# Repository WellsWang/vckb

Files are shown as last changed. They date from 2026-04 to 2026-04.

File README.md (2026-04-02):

# Vibe Coding Keyboard

## 简介

Vibe Coding Keyboard 是一个基于 ESP32-S3 的自定义键盘项目，支持 USB HID 键盘和鼠标功能。该键盘配备了一个 76x284 分辨率的 TFT-LCD 显示屏、9 个按键、1 个拨动开关和 1 个旋转编码器。通过配套的配置工具，可以灵活配置按键映射，支持多达 10 个键盘方案。



项目作者：Wells Wang (geek-logic.com)  
版本：0.1  
发布日期：2026/02/08  
许可证：GPL-3.0

## 功能特性

- **硬件核心**：ESP32-S3，具备原生 USB 接口
- **显示屏**：ST7789 驱动的 TFT-LCD，76x284 分辨率
- **输入设备**：
  - 9 个机械按键
  - 1 个拨动开关
  - 1 个旋转编码器（支持顺时针、逆时针和按下）
- **输出功能**：USB HID 键盘和鼠标
- **配置方案**：支持 10 个键盘映射方案，可切换激活
- **触发模式**：支持同时触发、顺序触发和粘滞触发
- **配置工具**：Python 桌面应用，支持实时配置和导入/导出配置

## 硬件要求

- ESP32-S3 开发板
- ST7789 TFT-LCD 显示屏 (76x284 分辨率)
- 9 个按键
- 1 个拨动开关
- 1 个旋转编码器
- 连接线和电源

### 引脚连接

#### LCD 显示屏 (ST7789)
- TFT_GND → GND
- TFT_VCC → 3.3V
- TFT_SCL → GPIO 12 (SCK)
- TFT_SDA → GPIO 11 (MOSI)
- TFT_RST → GPIO 9
- TFT_DC → GPIO 8
- TFT_CS → GPIO 10
- TFT_BL → GND

#### 按键和开关
- KEY0 → GPIO 3
- KEY1 → GPIO 4
- KEY2 → GPIO 5
- KEY3 → GPIO 6
- KEY4 → GPIO 7
- KEY5 → GPIO 14
- KEY6 → GPIO 15
- KEY7 → GPIO 16
- KEY8 → GPIO 17
- SW0 (拨动开关) → GPIO 38
- RT_BT (旋转编码器按钮) → GPIO 42
- RT_SA (旋转编码器 A) → GPIO 46
- RT_SB (旋转编码器 B) → GPIO 45

## 软件要求

- **固件**：
  - Arduino IDE
  - ESP32 板管理器
  - 所需库：Adafruit_GFX, Adafruit_ST7789, USB, USBHIDMouse, USBHIDKeyboard, EEPROM

- **配置工具**：
  - Python 3.x
  - Tkinter (通常随 Python 安装)
  - pyserial 库

## 安装和设置

### 固件烧录

1. 安装 Arduino IDE 和 ESP32 板管理器。
2. 安装所需库：Adafruit_GFX, Adafruit_ST7789, USBHID 等。
3. 打开 `src/Firmware/vckeyboard/vckeyboard.ino`。
4. 选择 ESP32-S3 板，设置 USB 模式为 USB-OTG。
5. 编译并上传固件到 ESP32-S3。

### 配置工具安装

1. 确保安装 Python 3.x。
2. 安装 pyserial：`pip install pyserial`
3. 运行 `src/Application/VCKBConfig.py`。

## 使用说明

1. 烧录固件后，键盘将作为 USB HID 设备连接到电脑。
2. 在正常使用模式长按旋转编码器可以进入设置模式，顺时针/逆时针旋转进行菜单项选择，短按旋转编码器为确定，长按旋转编码器为取消或这回退到上一级菜单。

## 远程配置工具

`VCKBConfig.py` 是一个基于 Tkinter 的桌面应用，提供以下功能：


- 串口选择和连接
- 读取/写入键盘配置
- 导入/导出二进制配置文件
- 实时预览和编辑按键映射
- 支持多方案管理

### 远程配置模式


1. 键盘在设置模式中选择`Remote Config`可以进入远程配置模式。
2. 键盘进入远程设置模式后，在PC端运行`VCKBConfig.py`可以进行远程设置。
3. 远程设置前，先要选择正确的串口端口号。
4. 默认的案件配置可以通过"导入"功能，读取同一文件夹下的`Default.bin`配置文件导入。
5. 点击"写入"将配置保存到键盘的 EEPROM。
6. 键盘将根据配置响应按键输入。

### 按键映射格式

每个按键支持：
- 短名称（最多 7 字符）
- 触发模式：同时触发、顺序触发、粘滞触发
- 最多 5 个键值组合（基于 USB HID 键值表）

## 项目结构

```
vckb/
├── 3D Models/                            # 外壳 3D 建模
│   ├── sketchup_src/                     # SketchUp 3D建模源文件
│   └── stl/                              # 3D 打印用模型文件
├── src/
│   ├── Application/                      # 配置工具
│   │   ├── VCKBConfig.py
│   │   └── Default.bin                   # 默认配置，供参考
│   ├── Firmware/                         # 固件代码
│   │   └── vckeyboard/
│   │       └── vckeyboard.ino
│   └── PCB/                              # 电路设计
│       ├── Gerbers/
│       │   └── VCKeyboard_Gerber_v1.zip  # PCB生产Gerber文件
│       ├── LCEDA_Project/                # EDA工程文件
│       │   └── VibeKeyboard.eprj2        # LCEDA电路设计工程源文件
│       └── Schematics/                   # 电路图
│           └── SCH_Schematic_v1.pdf      # 电路原理图
└── README.md                             # 本文件
```

## 后续计划

这个项目就是做着玩的，代码手搓没有很好的结构化，期待你参与开发一同完善，同时增加蓝牙和Wifi功能，做成无线键盘或者找到新的应用场景。

## 许可证

本项目基于 GPL-3.0 开源协议发布。欢迎使用、修改和分发，但请保留原作者信息和开源协议声明。

## 作者

Wells Wang  
网站：geek-logic.com  
邮箱：（请联系作者获取）

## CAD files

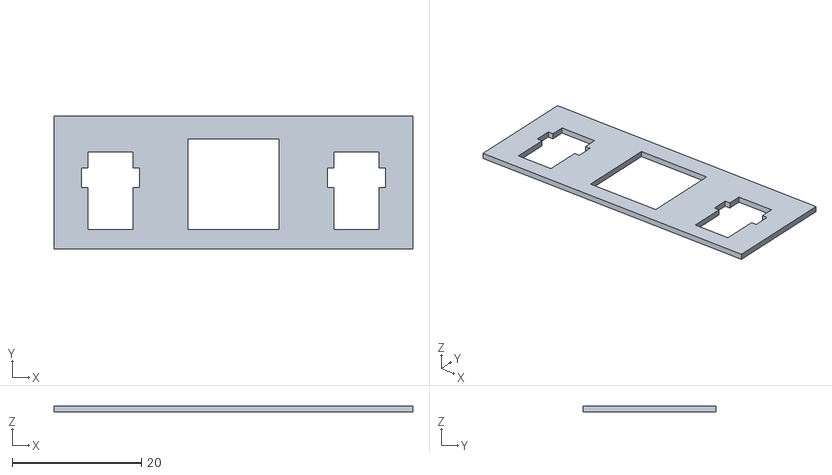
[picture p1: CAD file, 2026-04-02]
3D Models/stl/空格卫星轴定位板.stl
55.5 x 20.5 x 1.00

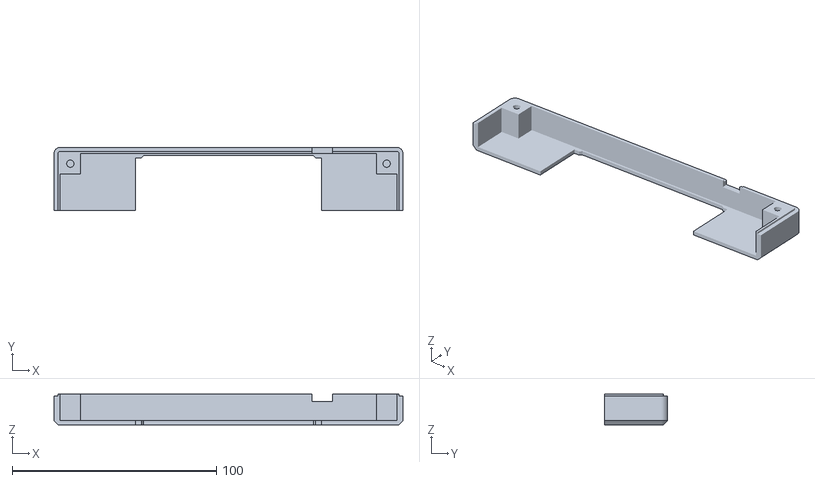
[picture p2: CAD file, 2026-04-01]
3D Models/stl/VibeCoding键盘上盖2.stl
171.0 x 31.0 x 15.0

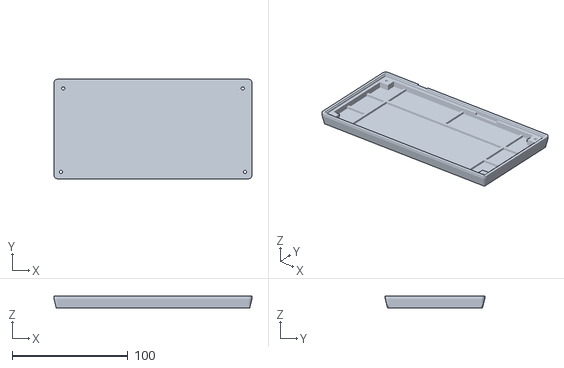
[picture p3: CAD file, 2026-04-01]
3D Models/stl/VibeCoding键盘底壳.stl
171.0 x 86.0 x 10.6

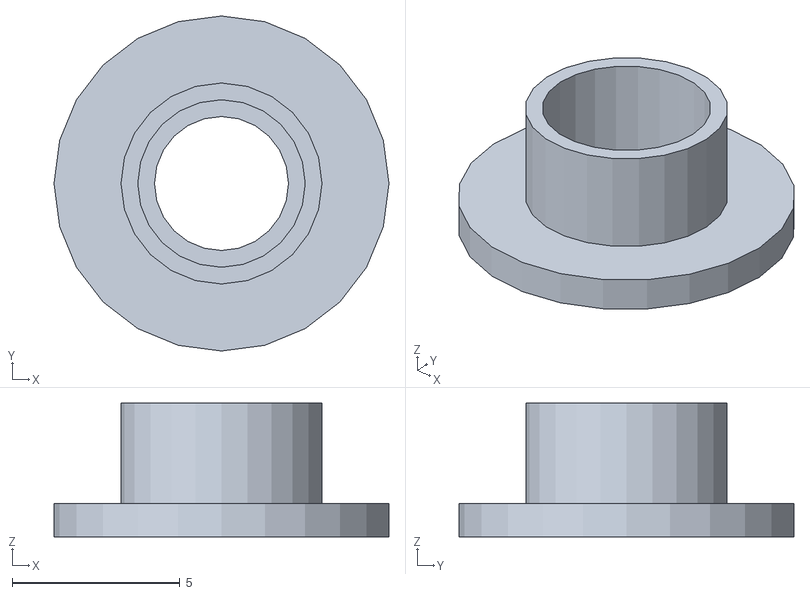
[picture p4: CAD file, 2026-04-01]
3D Models/stl/VibeCoding开关帽.stl
10.0 x 10.0 x 4.00

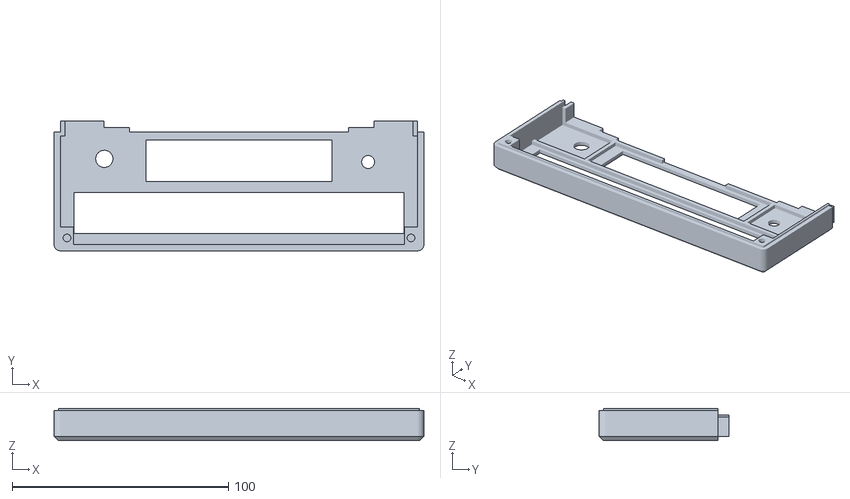
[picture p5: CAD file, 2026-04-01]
3D Models/stl/VibeCoding键盘上盖1.stl
171.0 x 60.0 x 15.0

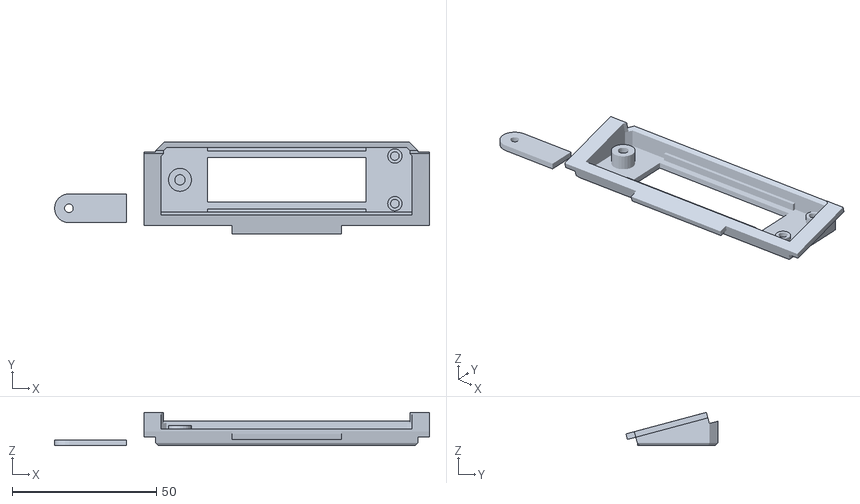
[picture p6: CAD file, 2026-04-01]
3D Models/stl/VibeCoding显示屏外壳.stl
130.0 x 31.9 x 11.6

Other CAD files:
3D Models/sketchup_src/开关帽.skp
3D Models/sketchup_src/显示屏外壳.skp
3D Models/sketchup_src/键盘上盖1.skp
3D Models/sketchup_src/键盘上盖2.skp
3D Models/sketchup_src/键盘底壳.skp

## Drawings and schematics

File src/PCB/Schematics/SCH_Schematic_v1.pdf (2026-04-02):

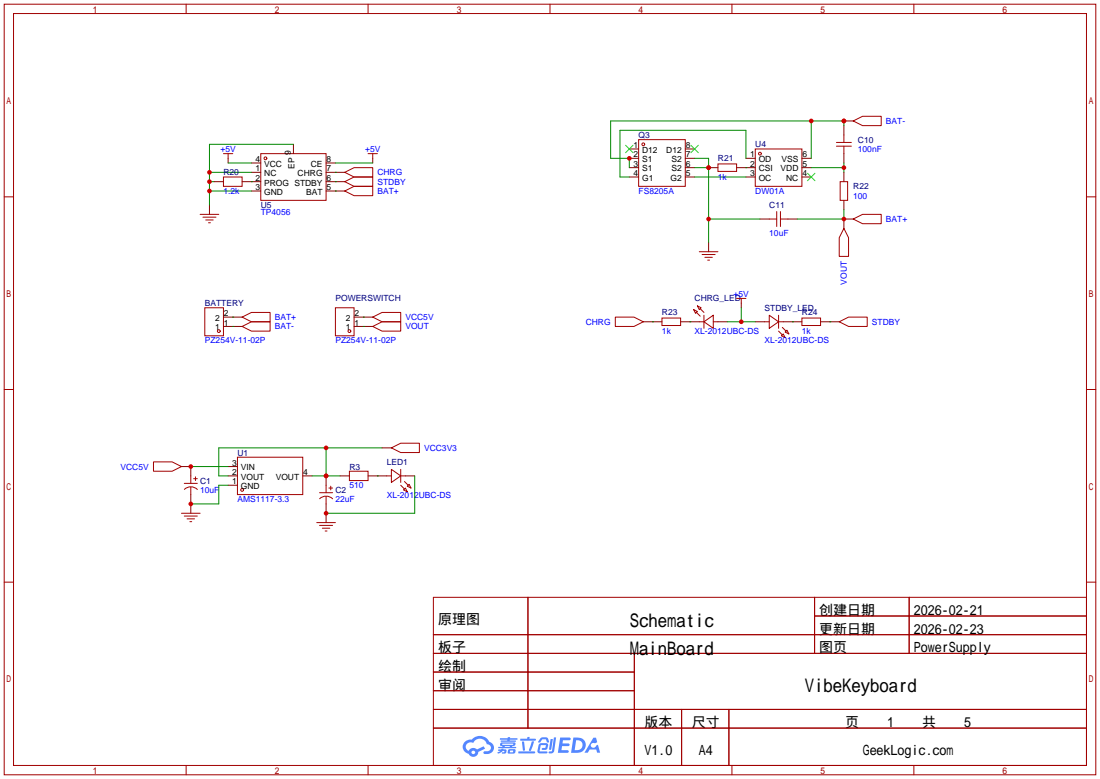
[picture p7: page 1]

原理图 | Schematic | 创建日期 | 2026-02-21

更新日期 | 2026-02-23

板子 | MainBoard | 图页 | PowerSupply
绘制 | | VibeKeyboard
审阅

V1.0 | A4 | GeekLogic.com

SBU2 B8 DN2 B7 DP2 B6 CC2 B5 VBUS B4A9 GND B1A12 SBU1 A8 DN1 A7 DP1 A6 CC1 A5 VBUS A4B9 GND A1B12

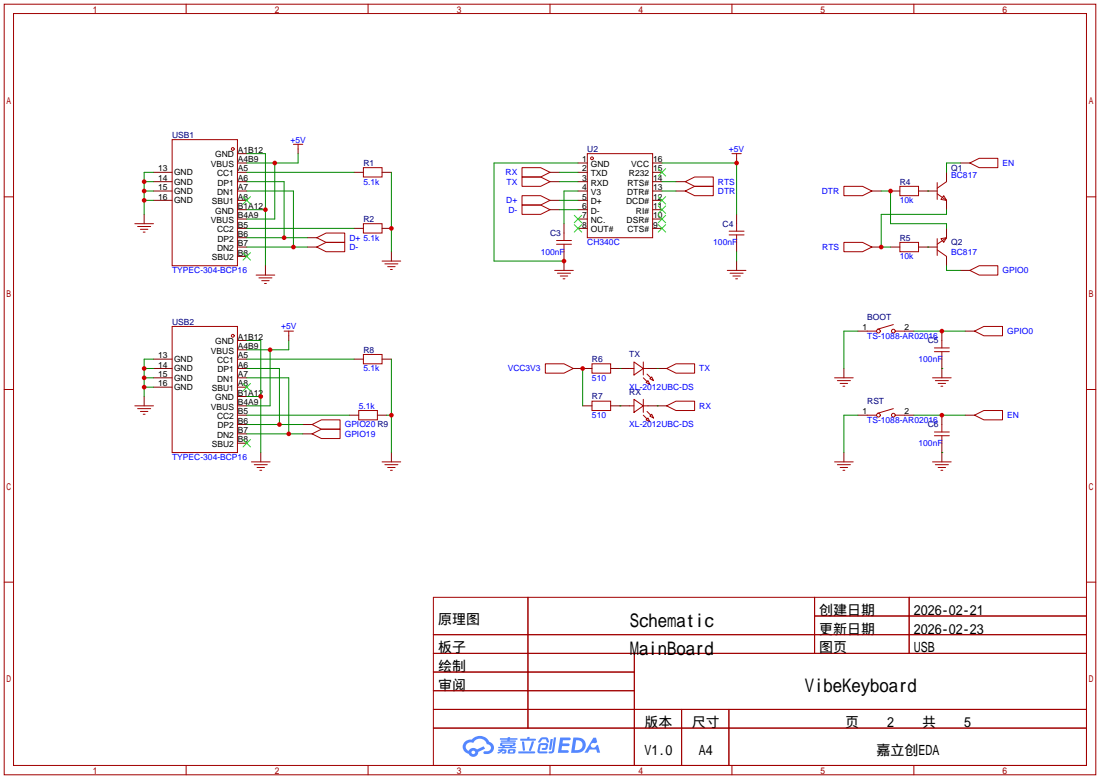
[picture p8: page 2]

DSR# 10 RI# 11 DCD# 12 DTR# 13 RTS# 14 R232 15 VCC 16

GND 16 GND 15 GND 14 GND 13

原理图 | Schematic | 创建日期 | 2026-02-21
板子 | MainBoard | 图页 | USB
绘制 | | VibeKeyboard
审阅

更新日期 | 2026-02-23

V1.0 | A4 | 嘉立创EDA

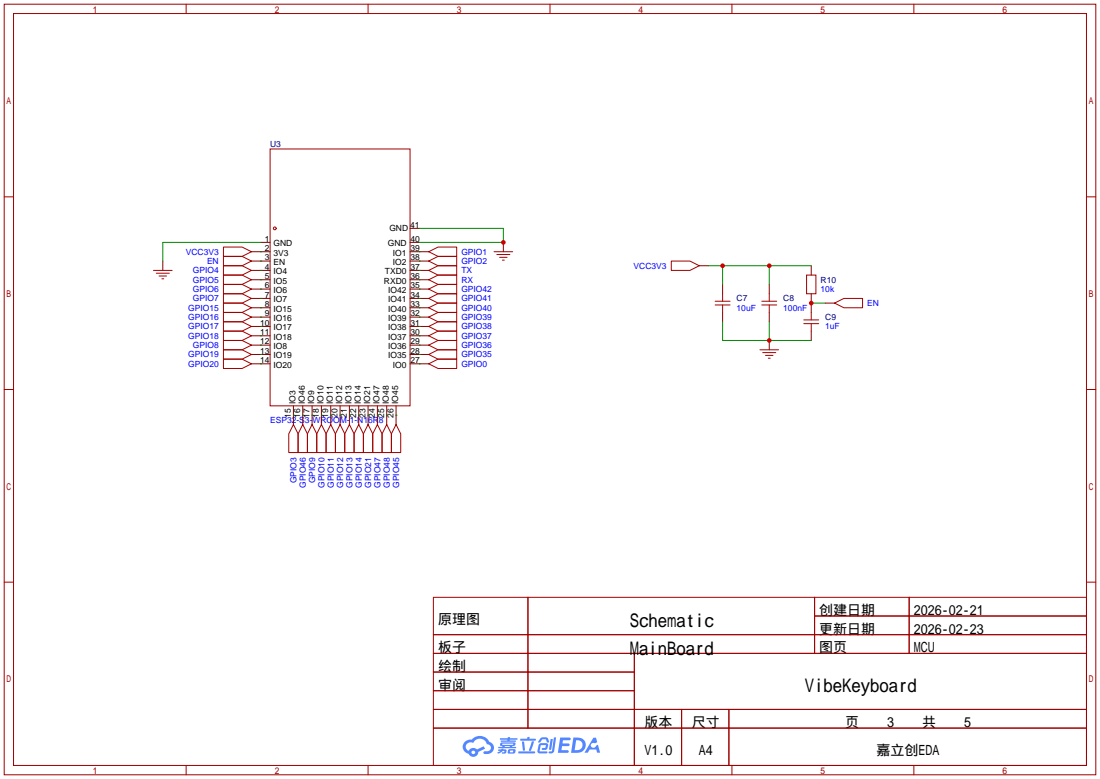
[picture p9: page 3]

原理图 | Schematic | 创建日期 | 2026-02-21
板子 | MainBoard | 图页 | MCU
绘制 | | VibeKeyboard
审阅

更新日期 | 2026-02-23

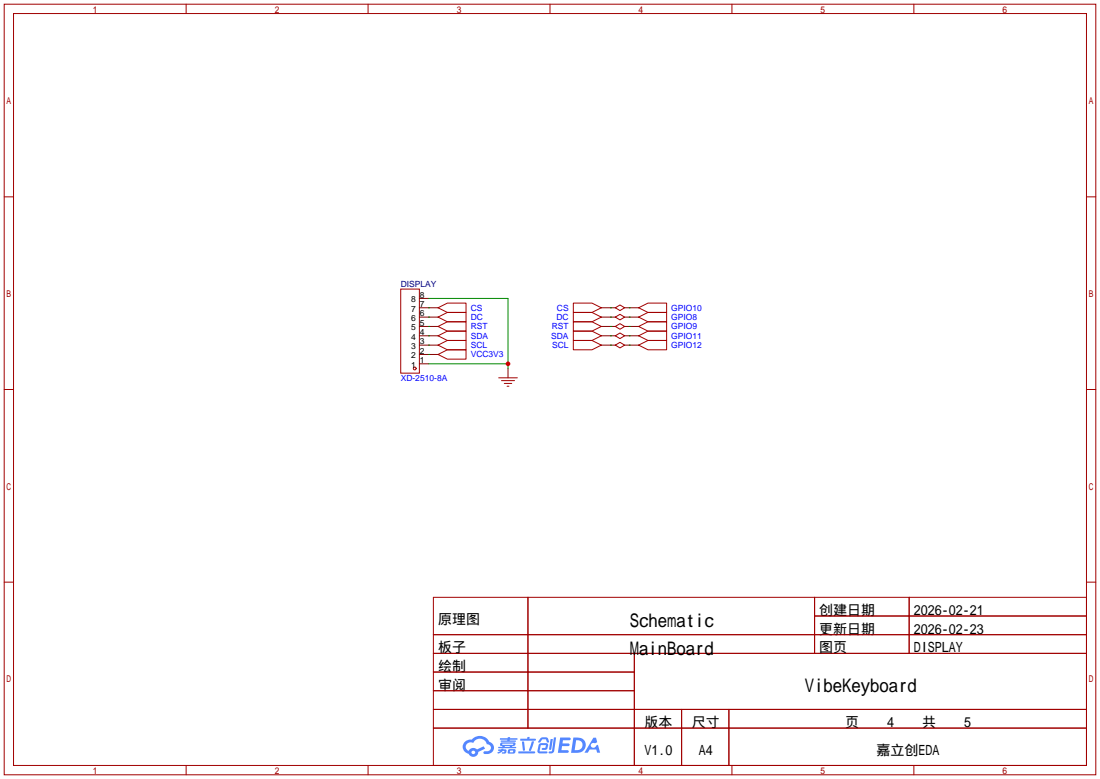
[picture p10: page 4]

原理图 | Schematic | 创建日期 | 2026-02-21

更新日期 | 2026-02-23

板子 | MainBoard | 图页 | DISPLAY
绘制 | | VibeKeyboard
审阅

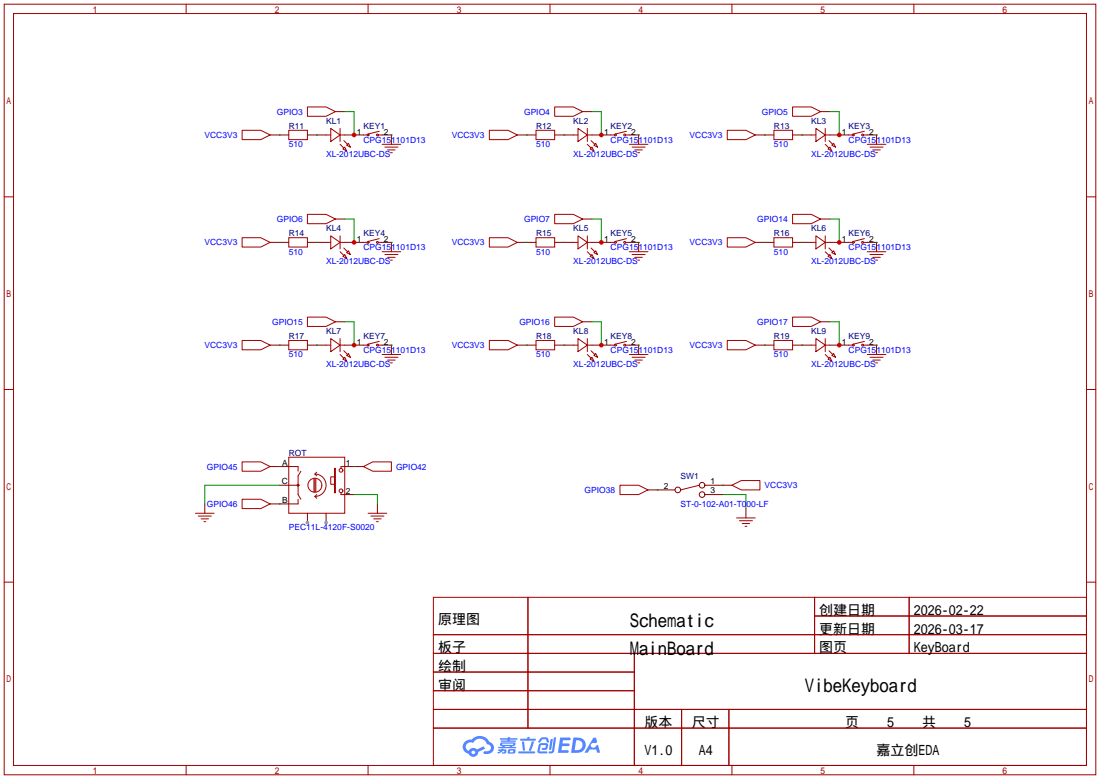
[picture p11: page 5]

原理图 | Schematic | 创建日期 | 2026-02-22

更新日期 | 2026-03-17

板子 | MainBoard | 图页 | KeyBoard
绘制 | | VibeKeyboard
审阅

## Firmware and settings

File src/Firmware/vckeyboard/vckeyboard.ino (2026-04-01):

/**************************************************************************
  Vibe Coding Keyboard
  ------------------------------------------------------------------------
  带有一个液晶显示屏的ESP32 S3 USB / 蓝牙自定义键盘

  液晶屏： 使用ST7789驱动的分辨率为76*284的TFT-LCD
  按键：
    拨动开关    x1
    按键        x9
    旋转编码器  x1
  
  硬件核心为 ESP32-S3，使用USB HID功能实现键盘和鼠标功能

  ------------------------------------------------------------------------
  
  作者： Wells Wang, geek-logic.com
  基于GPL-3.0开源协议发布，欢迎使用和修改，但请保留原作者信息和开源协议声明
  
  ------------------------------------------------------------------------
  
  版本 0.1 - 2026/02/08 初始版本，包含基本的显示和按键功能测试

 **************************************************************************/

///// EEPROM 设置
#include "EEPROM.h"
int addr = 0;
#define EEPROM_SIZE 2300     // EEPROM 大小，单位字节
#define EEPROM_VERSION 0x01 // EEPROM格式版本号，后续版本更新时可以通过修改此版本号来判断是否需要重新格式化EEPROM

///// LCD 设置
/**************************************************************************
LCD显示屏使用ST7789驱动，分辨率为76*284，连接方式为SPI接口
连接引脚：
  TFT_GND   - 连接到GND
  TFT_VCC   - 连接到3.3V
  TFT_SCL/K - 连接到数字引脚 12 (SCK)
  TFT_SDA   - 连接到数字引脚 11 (MOSI)
  TFT_RST   - 连接到数字引脚 9 (或设置为 -1 并连接到 Arduino RESET 引脚) 
  TFT_DC    - 连接到数字引脚 8 
  TFT_CS    - 连接到数字引脚 10
  TFT_BL    - 连接到GND
 **************************************************************************/
#include <Adafruit_GFX.h>    // Core graphics library
#include <Adafruit_ST7789.h> // Hardware-specific library for ST7789
#include <SPI.h>

#define TFT_CS        10
#define TFT_RST        9 // Or set to -1 and connect to Arduino RESET pin
#define TFT_DC         8
Adafruit_ST7789 tft = Adafruit_ST7789(TFT_CS, TFT_DC, TFT_RST); // 液晶屏幕

///// ESP32-S3 USB模式设置
#ifndef ARDUINO_USB_MODE
#error This ESP32 SoC has no Native USB interface
#elif ARDUINO_USB_MODE == 1
#warning This sketch should be used when USB is in OTG mode
void setup() {}
void loop() {}
#else

  #include "USB.h"
  #include "USBHIDMouse.h"
  #include "USBHIDKeyboard.h"
  USBHIDMouse Mouse;
  USBHIDKeyboard Keyboard;

  //按键引脚设置
  const int KEY0 = 3;
  const int KEY1 = 4;
  const int KEY2 = 5;
  const int KEY3 = 6;
  const int KEY4 = 7;
  const int KEY5 = 14;
  const int KEY6 = 15;
  const int KEY7 = 16;
  const int KEY8 = 17;

  const int SW0 = 38;     // 拨动开关
  const int RT_BT = 42;   // 旋转编码器按钮
  const int RT_SA = 46;   // 旋转编码器A
  const int RT_SB = 45;   // 旋转编码器B
  
  const unsigned long DEBOUNCE_MS = 15; // 按键去抖时间，单位毫秒
  
  // 按键状态结构体
  struct Key {
    uint8_t pin;
    bool lastState;        // 上一次读取的原始电平
    unsigned long lastChange; 
    bool pressed;          // 稳定的按下状态
  };

  // 定义按键数组，包含9个按键，初始状态为未按下（HIGH）
  Key keys[9] = {
    {KEY0, HIGH, 0, false},
    {KEY1, HIGH, 0, false},
    {KEY2, HIGH, 0, false},
    {KEY3, HIGH, 0, false},
    {KEY4, HIGH, 0, false},
    {KEY5, HIGH, 0, false},
    {KEY6, HIGH, 0, false},
    {KEY7, HIGH, 0, false},
    {KEY8, HIGH, 0, false}
  };

  int key_history[3] = {-1, -1, -1};  // 按键历史记录

  // 键值映射结构体
  struct Key_Value {
    String name;
    byte value;
  };

  // 键值映射表，包含常用键盘按键和功能键
  Key_Value key_val[105] = {
    {"None", 0x00},
    {"`", 0x60},
    {"1", 0x31},
    {"2", 0x32},
    {"3", 0x33},
    {"4", 0x34},
    {"5", 0x35},
    {"6", 0x36},
    {"7", 0x37},
    {"8", 0x38},
    {"9", 0x39},
    {"0", 0x30},
    {"-", 0x2D},
    {"=", 0x3D},
    {"Space", 0x20},
    {"A", 0x61},
    {"B", 0x62},
    {"C", 0x63},
    {"D", 0x64},
    {"E", 0x65},
    {"F", 0x66},
    {"G", 0x67},
    {"H", 0x68},
    {"I", 0x69},
    {"J", 0x6A},
    {"K", 0x6B},
    {"L", 0x6C},
    {"M", 0x6D},
    {"N", 0x6E},
    {"O", 0x6F},
    {"P", 0x70},
    {"Q", 0x71},
    {"R", 0x72},
    {"S", 0x73},
    {"T", 0x74},
    {"U", 0x75},
    {"V", 0x76},
    {"W", 0x77},
    {"X", 0x78},
    {"Y", 0x79},
    {"Z", 0x7A},
    {"[", 0x5B},
    {"]", 0x5D},
    {"\\", 0x5C},
    {";", 0x3B},
    {"'", 0x27},
    {",", 0x2C},
    {".", 0x2E},
    {"/", 0x2F},
    {"Left Ctrl", 0x80},
    {"Left Shift", 0x81},
    {"Left Alt", 0x82},
    {"Left GUI", 0x83},
    {"Right Ctrl", 0x84},
    {"Right Shift", 0x85},
    {"Right Alt", 0x86},
    {"Right GUI", 0x87},
    {"Up Arrow", 0xDA},
    {"Down Arrow", 0xD9},
    {"Left Arrow", 0xD8},
    {"Right Arrow", 0xD7},
    {"Menu", 0xED},
    {"Backspace", 0xB2},
    {"Tab", 0xB3},
    {"Return", 0xB0},
    {"ESC", 0xB1},
    {"Insert", 0xD1},
    {"Delete", 0xD4},
    {"Page Up", 0xD3},
    {"Page Down", 0xD6},
    {"Home", 0xD2},
    {"End", 0xD5},
    {"Num Lock", 0xDB},
    {"Caps Lock", 0xC1},
    {"F1", 0xC2},
    {"F2", 0xC3},
    {"F3", 0xC4},
    {"F4", 0xC5},
    {"F5", 0xC6},
    {"F6", 0xC7},
    {"F7", 0xC8},
    {"F8", 0xC9},
    {"F9", 0xCA},
    {"F10", 0xCB},
    {"F11", 0xCC},
    {"F12", 0xCD},
    {"Print Screen", 0xCE},
    {"Scroll Lock", 0xCF},
    {"Pause", 0xD0},
    {"Keypad /", 0xDC},
    {"Keypad *", 0xDD},
    {"Keypad -", 0xDE},
    {"Keypad +", 0xDF},
    {"Keypad Enter", 0xE0},
    {"Keypad 1", 0xE1},
    {"Keypad 2", 0xE2},
    {"Keypad 3", 0xE3},
    {"Keypad 4", 0xE4},
    {"Keypad 5", 0xE5},
    {"Keypad 6", 0xE6},
    {"Keypad 7", 0xE7},
    {"Keypad 8", 0xE8},
    {"Keypad 9", 0xE9},
    {"Keypad 0", 0xEA},
    {"Keypad .", 0xEB}
  };

  // 旋转编码器状态结构体
  struct RotateEncoder  {
    int pinA;
    int pinB;
    int pinBtn;
    bool lastStateA;
    bool lastStateB;
    bool lastStateBtn;
    bool pressed;
    unsigned long lastChangeA;
    unsigned long lastChangeB;
    unsigned long lastPressedBtn;
    unsigned long lastReleasedBtn;
  };

  // 定义旋转编码器，初始状态为未按下（HIGH）
  RotateEncoder rotEnc = {RT_SA, RT_SB, RT_BT, HIGH, HIGH, HIGH, false, 0, 0, 0, 0};
  #define ROT_ENC_LONG_PRESS_MS 1000 // 旋转编码器按钮长按时间，单位milliseconds
  

  byte keymap[12][6]; // 12个按键设置，每个按键最多支持5个键值的组合，每个键值1字节，前面1字节表示同时激活或顺序按下
  String currentSchemeName = "Scheme 1";
  
  bool needDisplayRefresh = true;

  // 菜单项结构体，包含菜单名称、操作函数和父菜单ID
  struct MenuItem {
    String name;
    void (*action)();
    int parentId; // 父菜单ID，-1表示顶级菜单
    byte subMode; // 子功能的模式
                  // subMode的值可以根据需要定义不同的功能模式，例如：
                  // 0：普通USB模式，正常运行中
                  // 1: 蓝牙模式，和普通USB模式一样，仅激活了蓝牙连接
                  // 2: 网络设置模式，进入后显示网络IP地址等信息可以通过访问网页进行配置
                  // 3：菜单操作界面，显示菜单操作界面
                  // 11：激活方案界面，显示当前方案列表，可以选择要激活的方案
                  // 12：修改方案界面，显示当前方案列表，可以选择要修改的方案
                  // 13：蓝牙设置界面，显示蓝牙设置选项，可以选择要修改的蓝牙设置
                  // 14：网络设置界面，显示网络设置选项，可以选择要修改的网络设置
  };

  void switchScheme();        // 前向声明激活方案的函数，以便在菜单项中使用
  void modifySchemeName();    // 前向声明修改方案名称的函数，以便在菜单项中使用
  void setKeyShortName();     // 前向声明修改按键短名称的函数，以便在菜单项中使用
  void toggleActive();        // 前向声明切换激活方案的函数，以便在菜单项中使用
  void toggleTriggerMode();   // 前向声明切换触发模式的函数，以便在菜单中使用
  void selectKey();           // 前向声明选择按键值得函数，以便在菜单项中使用
  void remoteConfigMode();    // 前向声明远程配置模式函数，以便在菜单项中使用

  // 定义菜单项，包含顶级菜单和子菜单
  #define MENU_SIZE 41
  #define IDX_SCHEME_START 8
  #define IDX_KEY_START 21
  #define IDX_KEY_VALUE_START 36

  MenuItem menu[MENU_SIZE] ={                                 // ID
    {"Normal", nullptr, -1, 0},                               // 0
    {"Settings", nullptr, -1, 3},                             // 1
    {"Remote Config",  remoteConfigMode, -1, 2},              // 2
    {"Primary Scheme", switchScheme, 1, 11},                  // 3
    {"Secondary Scheme", switchScheme, 1, 12},                // 4
    {"Modify Scheme", nullptr, 1, 4},                         // 5
    {"Bluetooth Settings", [](){}, 1, 13},                    // 6
    {"Network Settings", [](){}, 1, 14},                      // 7
    {"Scheme 1", nullptr, 5, 3},                              // 8
    {"Scheme 2", nullptr, 5, 3},                              // 9  
    {"Scheme 3", nullptr, 5, 3},                              // 10
    {"Scheme 4", nullptr, 5, 3},                              // 11
    {"Scheme 5", nullptr, 5, 3},                              // 12
    {"Scheme 6", nullptr, 5, 3},                              // 13
    {"Scheme 7", nullptr, 5, 3},                              // 14
    {"Scheme 8", nullptr, 5, 3},                              // 15
    {"Scheme 9", nullptr, 5, 3},                              // 16
    {"Scheme 10", nullptr, 5, 3},                             // 17
    {"Scheme Name", modifySchemeName, 8, 21},                 // 18
    {"Active / Deactive", toggleActive, 8, 25},               // 19
    {"Key Mapping", nullptr, 8, 5},                           // 20
    {"Key 1", nullptr, 20, 3},                                // 21
    {"Key 2", nullptr, 20, 3},                                // 22
    {"Key 3", nullptr, 20, 3},                                // 23
    {"Key 4", nullptr, 20, 3},                                // 24
    {"Key 5", nullptr, 20, 3},                                // 25
    {"Key 6", nullptr, 20, 3},                                // 26
    {"Key 7", nullptr, 20, 3},                                // 27
    {"Key 8", nullptr, 20, 3},                                // 28
    {"Key 9", nullptr, 20, 3},                                // 29
    {"RotEnc Clockwise", nullptr, 20, 3},                     // 30
    {"RotEnc Counter Clockwise", nullptr, 20, 3},             // 31
    {"RotEnc Button", nullptr, 20, 3},                        // 32
    {"Modify Key Value", nullptr, 21, 3},                     // 33
    {"Set Trigger Mode", toggleTriggerMode, 21, 31},          // 34
    {"Set Key Name", setKeyShortName, 21, 32},                // 35
    {"Key Value 1", selectKey, 33, 35},                       // 36
    {"Key Value 2", selectKey, 33, 35},                       // 37
    {"Key Value 3", selectKey, 33, 35},                       // 38
    {"Key Value 4", selectKey, 33, 35},                       // 39
    {"Key Value 5", selectKey, 33, 35},                       // 40
  };

  int currentMenuId = 1; // 当前菜单ID，初始为0
  int prevMenuId = 0;   // 上一个菜单ID
  int nextMenuId = 0;   // 下一个菜单ID
  int currentMode = 0;     // 当前功能模式，初始为0

  byte currentSchemeId = 1; // 当前激活的方案ID，初始为1
  byte schemeId = 1;    // 当前正在修改的方案ID，初始为1
  byte nextSchemeId = 1;    // 下一个方案ID
  byte prevSchemeID = 1;
  byte activeSchemeId;
  int pos = 0; // 当前输入位置
  bool isActive; // 当前方案是否激活
  bool primary = true; // 是否为主方案，方案切换用
  byte keyId = 0;
  int keyIndex = 0; //当前键值索引
  #define KEY_INTERVAL 50   //顺序按键间隔时间ms
  #define KEY_SHORT_NAME_LENGTH 7 // 按键短名称字符串长度

  byte serialMode = 'N';      // 串口模式，N 未连接，W 等待链接，R 接收，T 发送
  unsigned long serialStart = 0;        // 串口开始发送接收时间
  int bytesCount = 0;         // 串口接收数据计数器
  char configData[EEPROM_SIZE];   // 配置数据
  #define SER_TIMEOUT 60      // 串口信息发送接收timeout时长，60秒

  struct Scheme {
    String name;
    bool active;
    byte keymap[12][6];
    String keyname[12];
  };
  Scheme schemes[10]; // 最多支持10组方案



  //////////////////// DATA 相关 ////////////////////
  
  // 格式化EEPROM
  void formatEEPROM() {
    /*
      EEPROM存储信息格式：
      地址范围      内容
      0             当前激活的键盘方案ID，1字节，默认值 0x01，即方案1
      1             键盘方案的总数量，1字节，默认值 0x0A , 10组方案
      2             设置顺序按下时的时间间隔，单位10毫秒，1字节，默认值 0x05，即50毫秒
      3             快速切换的第二套方案ID，1字节，默认值0x01，即方案1
      4-94          保留空间，未来存放蓝牙、网络等配置信息
      95            EEPROM格式版本号，1字节，默认值0x01，后续版本更新时可以通过修改此版本号来判断是否需要重新格式化EEPROM
      
      // 后续共10组96字节，每组表示一个方案的按键映射内容
      96-191        方案1的按键映射内容，96字节
        96字节内容格式：
          0         是否激活此方案，0不激活，1激活，1字节，默认值只有方案1为1，其余为0
          1-23      方案名称，23字节，最多支持23个字符的方案名称，超过部分会被截断，默认值为"Scheme {ID}"
          24-95     方案的按键映射内容，72字节，共9个按键加旋转编码器的两个方向和一个按键的设置（12个设置），每个按键6个字节
            每个按键的6字节内容格式：
              0         同时激活或顺序按下，0为同时激活，1为顺序按下，1字节，后续扩展可能增加更多的激活方式，默认值为0
              1-5       5个键值，每个1字节，表示按键按下时要发送的键值，最多支持5个键值的组合，超过部分会被忽略，键值参考USB HID键盘使用的键值表，0表示无按键，默认值为0

      192-287       方案2的按键映射内容，96字节
      ...
      960-1055       方案10的按键映射内容，96字节  
      1056-1099     保留空间
      1100-2299     1200字节按键短名称，10个按键配置方案，每个方案12个按键，每个按键10字节空间
        1100-1219   120个字节 方案一的按键短名称
          1100-1109 方案一的第一个按键的短名称
          ...
          1210-1219 方案二的第十二个按键的短名称
          ...
          ...
          ...
    */

    // 初始化EEPROM内容
    // 地址0：当前激活的键盘方案ID，默认值0x01（方案1）
    EEPROM.write(0, 0x01);
    
    // 地址1：键盘方案总数，默认值0x0A（10组方案）
    EEPROM.write(1, 0x0A);
    
    // 地址2：顺序按下时的时间间隔（单位10毫秒），默认值0x05（50毫秒）
    EEPROM.write(2, 0x05);

    // 地址3：快速切换的第二套方案ID，默认值0x01（方案1），两套方案相同表示不切换
    EEPROM.write(3, 0x01);
    
    // 地址4-95：保留空间，初始化为0
    for (int i = 4; i < 95; i++) {
      EEPROM.write(i, 0);
    }
    
    // 地址95：EEPROM格式版本号
    EEPROM.write(95, EEPROM_VERSION);

    // 地址96-1055：10组方案数据，每组96字节
    for (int scheme = 0; scheme < 10; scheme++) {
      int baseAddr = 96 + scheme * 96;
      
      // 第0字节：是否激活此方案（只有方案1激活）
      EEPROM.write(baseAddr, (scheme == 0) ? 1 : 0);
      
      // 第1-23字节：方案名称
      String schemeName = "Scheme " + String(scheme + 1);
      for (int j = 0; j < 23; j++) {
      EEPROM.write(baseAddr + 1 + j, (j < schemeName.length()) ? schemeName[j] : 0);
      }
      
      // 第24-95字节：按键映射内容（12个按键×6字节），初始化为0
      for (int i = 24; i < 96; i++)
        EEPROM.write(baseAddr + i, 0);
      
      // 初始化按键短名称
      for (int i = 0; i < 120; i++) 
        EEPROM.write(1100 + scheme * 120 + i, 0);
    }
    EEPROM.commit();
  }

  //读取当前按键方案名称
  String getSchemeName(byte id) {
    /*
      读取指定ID的方案名称
      参数：
        id：方案ID，范围1-10，对应EEPROM中地址96-1055的10组方案数据
      返回值：
        方案名称字符串，最多支持23个字符，超过部分会被截断
    */
    if (id < 1 || id > 10) {
      Serial.println("Invalid scheme ID");
      return "";
    }
    int baseAddr = id * 96;
    String schemeName = "";
    for (int i = 0; i < 23; i++) {
      char c = EEPROM.read(baseAddr + 1 + i);
      if (c == 0) break; // 遇到字符串结束符
      schemeName += c;
    }
    return schemeName;
  }

  //读取按键短名称

  String getKeyShortName(byte scheme_id, byte key_id){
    /*
      获取按键的短名称
      
      从EEPROM中读取指定方案和按键的短名称。如果未设置名称或名称为空，
      则返回默认名称 "KEYx"（x为按键ID）。
      
      参数：
      scheme_id 方案ID，用于定位EEPROM中不同方案的存储位置
      key_id 按键ID，用于定位该方案内的特定按键
      
      返回值：
      String 按键的短名称，长度最多为KEY_SHORT_NAME_LENGTH个字符，
            如果未设置则返回默认名称"KEYx"
    
      细节说明：
        - 基础地址：1100
        - 地址计算：baseAddr + scheme_id * 120 + key_id * 10 + i
        - 每个按键分配10字节空间存储短名称
        - 字符串以null终止符(0)或达到最大长度时结束
      
      注意： 确保scheme_id和key_id的有效性，避免越界访问EEPROM
    */
    int baseAddr = 1100;
    String short_name = "";
    for (int i = 0 ; i < 10 ; i++){
      char c = EEPROM.read(baseAddr + scheme_id * 120 + key_id * 10 + i);
      if (c==0 || i == KEY_SHORT_NAME_LENGTH) break; // 字符串结束或超过最大长度
      short_name += c;
    }
    if (short_name == "") short_name = "KEY" + String(key_id); //默认名称
    return short_name;
  }
  
  void getSchemeList() {
    /*
      获取所有方案的名称和激活状态，并存储在全局变量schemes数组中
      参数：
        无
      返回值：
        无，获取到的方案信息会存储在全局变量schemes数组中
    */
    for (byte id = 1; id <= 10; id++) {
      int baseAddr = id * 96;
      schemes[id - 1].active = (EEPROM.read(baseAddr) == 1);
      schemes[id - 1].name = getSchemeName(id);
      menu[IDX_SCHEME_START - 1 + id].name = schemes[id - 1].name; // 更新菜单项名称
      for (int i = 0; i < 12; i++) {
        for (int j = 0; j < 6; j++) {
          schemes[id - 1].keymap[i][j] = EEPROM.read(baseAddr + 24 + i * 6 + j);
        }
        schemes[id - 1].keyname[i] = getKeyShortName(id -1, i);
      }
    }
  }

  byte findActiveSchemeId(byte curId, bool direction){
    /*
      在EEPROM中查找下一个或上一个激活的方案ID
      参数：
        curId：当前方案ID，范围1-10
        direction：查找方向，true表示顺时针（下一个），false表示逆时针（上一个）
      返回值：
        下一个或上一个激活的方案ID，如果没有找到则返回当前方案ID 
    */
    int startAddr = curId * 96; // 当前方案的EEPROM地址
    int step = direction ? 96 : -96; // 步长，根据方向决定是向后还是向前查找
    int addr = startAddr; // 从当前方案开始查找
    do {
      addr += step; // 移动到下一个或上一个方案的地址
      if (addr < 96) {
        addr = 960; // 如果越过第一个方案，则跳转到最后一个方案
      } else if (addr > 960) {
        addr = 96; // 如果越过最后一个方案，则跳转到第一个方案
      }
      if (EEPROM.read(addr) == 1) { // 检查该方案是否激活
        return byte (addr / 96) ; // 返回找到的激活方案ID
      }
    } while (addr != startAddr); // 如果回到起始地址，说明没有找到其他激活的方案
    return curId; // 没有找到其他激活的方案，返回当前方案ID
  }

  void updateMenuParentID(int menu_id, int start_idx, int end_idx){
    /*
      更新菜单项的父菜单ID，将指定范围内的菜单项的父菜单ID设置为指定的菜单ID
      参数：
        menu_id：新的父菜单ID
        start_idx：起始索引
        end_idx：结束索引
      返回值：无
    */
    for (int i = start_idx; i < end_idx; i++) 
      menu[i].parentId = menu_id; // 将修改按键映射的菜单项的父菜单ID
  }

  // 更新按键历史记录
  void updateKeyHistory(int key_index){
    /*
      更新按键历史记录，将最新的按键索引添加到历史记录中
      参数：
        key_index：按键索引
      返回值：无
    */
    key_history[0] = key_history[1];
    key_history[1] = key_history[2];
    key_history[2] = key_index;
  }

  // 根据键值获取键号索引
  int getKeyCodeIndex(byte val){
    /*
      根据键值查找对应的键号索引
      参数：
        val：键值
      返回值：键号索引，如果未找到返回-1
    */
    for (int i = 0; i < 105; i++){
      if (key_val[i].value == val)
        return i;  
    }
    return -1;
  }


  //////////////////// UI相关 ////////////////////

  // 绘制菜单项
  void drawMenuItem(int selectedId) {
    /*
      绘制指定父菜单ID下的菜单项列表
      如果菜单项数目大于三项，则需要实现滚动显示功能，尽可能让选中项显示在屏幕中间，并且在选中项上方和下方各显示一个菜单项，如果选中项在顶部或底部，则优先显示选中项和其相邻的两个菜单项
      同时更新prevMenuId和nextMenuId变量，以便在用户按下旋转编码器时能够正确地切换菜单项。
      当选中项为第一项时，prevMenuId应该指向最后一项，nextMenuId指向第二项；当选中项为最后一项时，prevMenuId应该指向倒数第二项，nextMenuId指向第一项；其他情况下prevMenuId指向选中项的前一项，nextMenuId指向选中项的后一项。
      参数：
        parentId：父菜单ID，-1表示顶级菜单
        selectedId：当前选中的菜单项ID
      返回值：
        无，菜单项会直接绘制到屏幕上
    */
   
    // 找到所有属于该父菜单的菜单项
    int menuItems[MENU_SIZE];
    int menuCount = 0;
    for (int i = 0; i < MENU_SIZE; i++) {
      if (menu[i].parentId == menu[selectedId].parentId) {
        menuItems[menuCount++] = i;
      }
    }
    
    if (menuCount == 0) return;
    
    // 找到选中项在该父菜单中的索引
    int selectedIndex = -1;
    for (int i = 0; i < menuCount; i++) {
      if (menuItems[i] == selectedId) {
      selectedIndex = i;
      break;
      }
    }
    if (selectedIndex == -1) selectedIndex = 0;
    
    // 更新prevMenuId和nextMenuId
    currentMenuId = selectedId;
    prevMenuId = menuItems[(selectedIndex - 1 + menuCount) % menuCount];
    nextMenuId = menuItems[(selectedIndex + 1) % menuCount];
    
    // 确定显示的起始项索引
    int startIndex = (selectedIndex - 1 + menuCount) % menuCount;

    // 绘制菜单项（最多显示3项）
    tft.setTextSize(1);
    int displayCount = (menuCount > 3) ? 3 : menuCount;
    int i;
    for (i = 0; i < displayCount; i++) {
      int itemIndex = (startIndex + i) % menuCount;
      int itemId = menuItems[itemIndex];
      bool isSelected = (itemIndex == selectedIndex);
      
      tft.setTextColor(isSelected ? ST77XX_RED : ST77XX_WHITE);
      tft.fillRect(0, 20 + i * 16, tft.width(), 20, isSelected ? ST77XX_WHITE : ST77XX_BLACK);
      tft.setCursor(10, 24 + i * 16 );
      tft.print(menu[itemId].name);
    }

    for (; i < 3; i++) {
      tft.fillRect(0, 20 + i * 16, tft.width(), 20, ST77XX_BLACK);
    }

  }

  void drawSubMenu(int id){
    /*
      绘制指定ID的子菜单项
      参数：
        id：菜单项ID
      返回值：无
    */
    for (int i = 0; i < MENU_SIZE; i++) {
      if ( menu[i].parentId == id) {
        drawMenuItem(i);
        break;
      }
    }
  }

  void drawSaveButton(bool inverse){
    /*
      绘制保存按钮，根据inverse参数决定是否反白显示
      参数：
        inverse：是否反白显示，true表示反白显示，false表示正常显示
      返回值：无
    */
    tft.fillRect(240, 60, 40, 16, inverse ? ST77XX_WHITE : ST77XX_BLACK);
    if (!inverse) {
      tft.drawRect(240, 60, 40, 16, ST77XX_WHITE); // 画边框
    } 
    tft.setCursor(248, 64);
    tft.setTextColor(inverse ? ST77XX_RED : ST77XX_WHITE);
    tft.print("Save");
  }

  char updateCurrentText(char currentChar, int direction, bool inverse = true) {
    /*
      更新当前选择字符的显示，同时更新schemes中对应方案名称的字符，以便在修改方案名称时能够实时预览输入的效果
      根据pos（当前第几个字符）来确定屏幕上显示的位置，以及确定schemes中对应方案名称中的第几个字符，当前正在修改的字符反白显示。
      修改的字符为当前位置的下一个或前一个字符（ASCII码），可用于修改的ASCII字符范围为32-126，超过范围时循环回到起始或结束位置。
      参数：
        currentChar: 当前的字符
        direction：方向，1 表示当前字符下一个字符，-1 表示前一个字符, 0表示当前字符
      返回值：  变更后的字符，更新后的文本会直接显示在屏幕上
    */
    //char currentChar = currentSchemeName[pos]; // 获取当前字符

    if (currentChar < 32 || currentChar > 126) currentChar = 32;

    if (direction == 1) {
      currentChar++; // 向下一个字符移动
      if (currentChar > 126) currentChar = 32; // 如果超出范围，循环到起始字符
    } else if (direction == -1) {
      currentChar--; // 向前一个字符移动
      if (currentChar < 32) currentChar = 126; // 如果超出范围，循环到结束字符
    }

    //currentSchemeName[pos] = currentChar; // 更新currentSchemeName中的字符

    // 在屏幕上更新显示
    tft.fillRect(10 + pos * 6, 36, 6, 16, (inverse ? ST77XX_WHITE : ST77XX_BLACK));
    tft.setCursor(10 + pos * 6, 40);
    tft.setTextColor(inverse ? ST77XX_RED : ST77XX_WHITE);
    tft.print(currentChar);

    return currentChar;
  }
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
  void loop() {
    /*
      Arduino主循环函数，不断检查按键状态和处理串口通信
      参数：无
      返回值：无
    */
    // 检查按键状态
    if (currentMode == 0) {
      checkKey(keys[0], [](){TriggerKey(0);});
      checkKey(keys[1], [](){TriggerKey(1);});
      checkKey(keys[2], [](){TriggerKey(2);});
      checkKey(keys[3], [](){TriggerKey(3);});
      checkKey(keys[4], [](){TriggerKey(4);});
      checkKey(keys[5], [](){TriggerKey(5);});
      checkKey(keys[6], [](){TriggerKey(6);});
      checkKey(keys[7], [](){TriggerKey(7);});
      checkKey(keys[8], [](){TriggerKey(8);});
    }

    checkRotateEncoder(rotEnc, 
      onRotateEnc_CW,
      onRotateEnc_CCW,
      onRotateEnc_ButtonPressed,
      onRotateEnc_ButtonLongPressed
    );

    bool sw = bool(digitalRead(SW0));
    if (sw != primary) {
      primary = sw;
      quickSwitchScheme();
    }

    checkSerial();


  }

#endif /* ARDUINO_USB_MODE */

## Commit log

2026-04-01 Initial project
    [VibeCoding开关帽.stl, VibeCoding显示屏外壳.stl, VibeCoding键盘上盖1.stl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]
2026-04-02 Add schematics and PCB layout
